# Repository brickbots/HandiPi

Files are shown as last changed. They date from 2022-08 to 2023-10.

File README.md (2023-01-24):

# HandiPi

Handheld RPI4 based computer with 36-key tactile keyboard and display

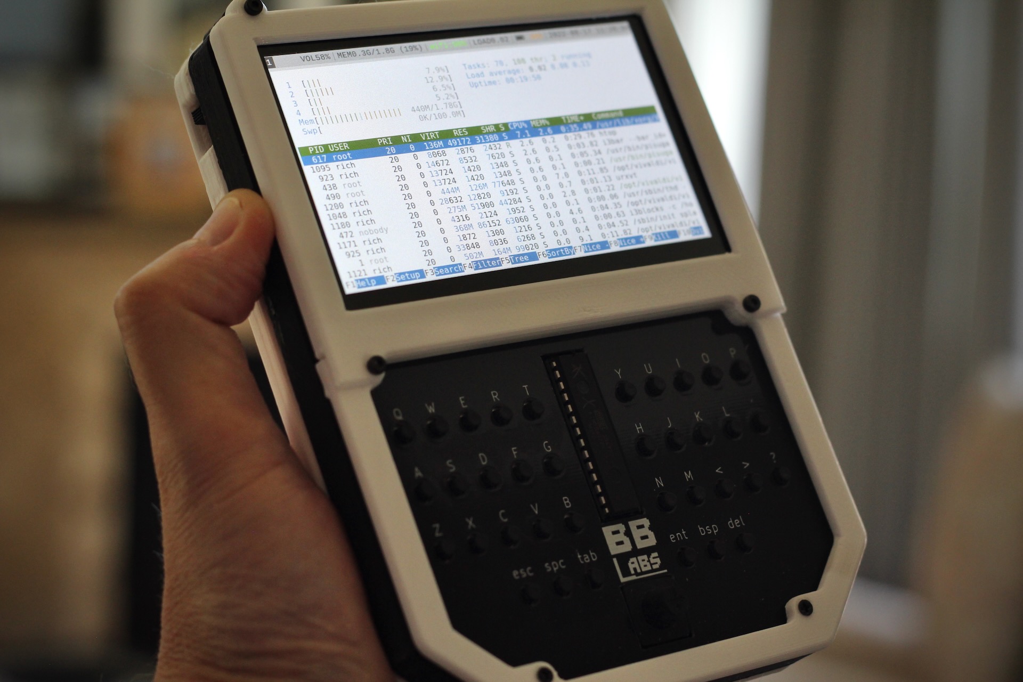
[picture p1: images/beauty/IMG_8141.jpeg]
The HandiPi


## What is it?

Glad you asked.. it's a fully functional linux computer with:
* A Raspberry Pi 4
* Custom 36-key keyboard with 5 way directional buton based around an Atmega328
* 4.3" DSI touchscreen display
* PiSugar power controller with 5000mah battery

It runs for about 4 hours with general terminal use and is pretty useful on it's own, but you can hook 
up external monitors and other USB peripherals if you need more screen or typing space.

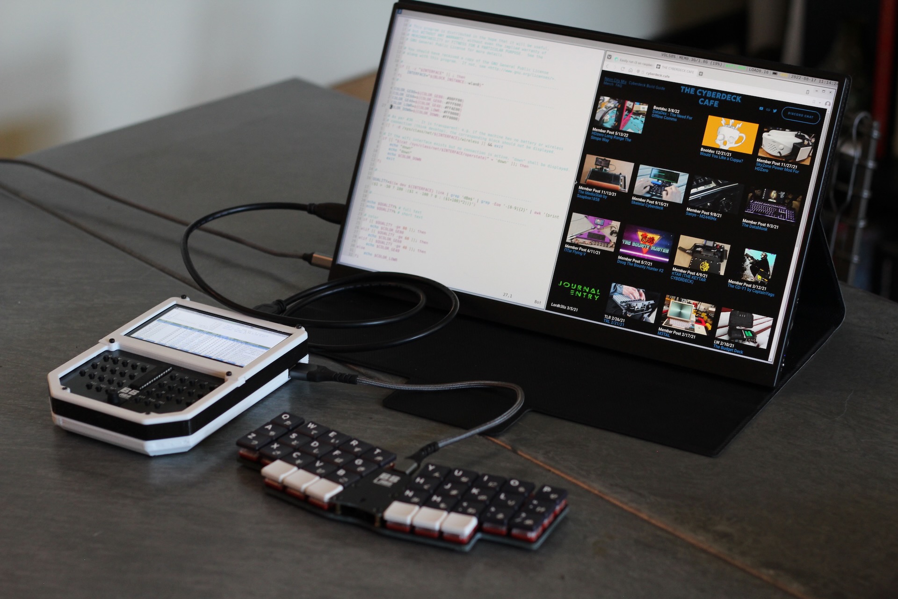
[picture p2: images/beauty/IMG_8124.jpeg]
Full work mode!


The keyboard runs QMK and interfaces to the Pi via USB, so it's fully configurable.  I really like the
[Miryoku](https://github.com/manna-harbour/miryoku) layout and use it on all my keyboards...so that's
what the physical button layout is based around.  The switches are Diptronic DTS63K tactiles with 1Nm 
of actuation force.  They look the same as the generic ones, but it's worth the few extra dollars as 
they feel so much better to type on.  It's still a thumb-typing experience, but the limited number of
keys and the well thought out layering system of Miryoku makes it a suprisingly useful keyboard!

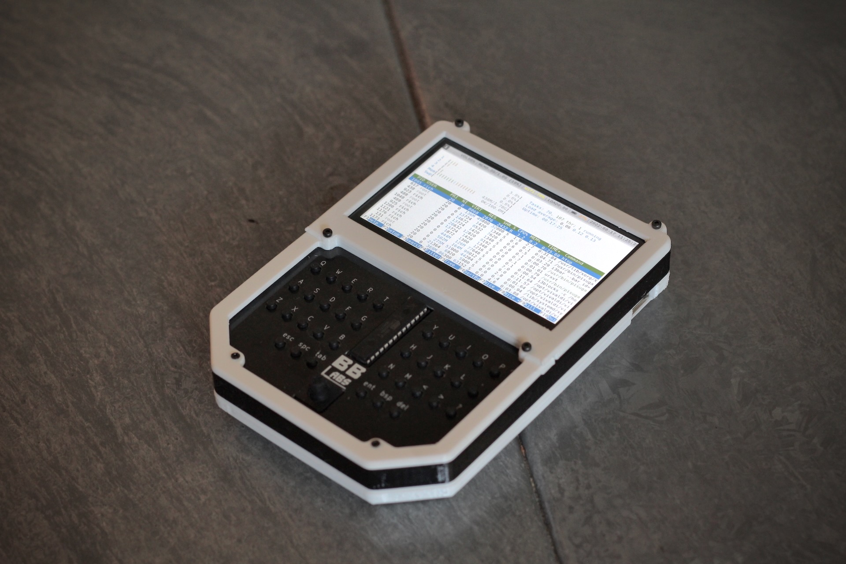
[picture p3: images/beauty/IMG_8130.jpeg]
It's a keyboard


## Oh god, why?

Well.. it all started when I picked up the PCB's for the 
[PICOmputer](https://www.tindie.com/products/bobricius/picomputer-rp2040-raspbbery-pico-qwerty-devkit/) 
made by [Bobricius](https://www.tindie.com/stores/bobricius/).  It's a sort of carrier board for the 
Raspberry Pi PICO that includes a keyboard using 6mm pushbutton tactile switches and a display.  It's 
simple, but it really opens up some fun potential.  I ended up 3d printing a case for mine and adding
a battery with charging to make it a neat little toy to play with.  Along the way, I was really
impressed with how well the keyboard actually worked.. even though I didn't follow his advice and bought
cheaper switches with higher actuation force.

When it came time to replace the Orange Pi based desktop PC I used at my workbench I grabbed the RPI4 I ordered
early in the pandemic and had been hording.  I was just going to put it in a boring case, but then I got 
to thinking about the PICOmputer and wondering if I could build a case with a screen and keyboard.  I'd 
still use the computer with a monitor, keyboard and trackball at my desk most of the time, but I could 
grab it and have my workbench computer with me if I wanted to go hack at a friends house or makerspace.

So that's where the idea came from, and the rest was just balancing the screen size with portability and
thinking hard about thumb-typing layouts....

## Designing a tiny keyboard

I've built a good number of keyboards in my time, and even [designed](https://github.com/brickbots/chocV)
a [couple](https://github.com/brickbots/slabv).  Most of the keyboards I've built rely on a pre-assembled 
Pro-Micro style controller, but I just didn't think I'd have the space to use that trick here.  There are 
many good refrence designs for the basic AtMega circuit, and I can
solder surface mount diodes okay, but I realy didn't think I'd have the skills to do a fine-pitch 
AtMega surface mount package without a lot of pain and suffering.  It was then that I remembered the first
keyboard I ever built.... the [Plaid](https://github.com/hsgw/plaid)!

The Plaid is a really neat 4x12 ortho keyboard built using ALL throughhole components!  It uses virtual
usb on an AtMega328 which is one of the few AtMega versions availabe in a DIPP package.  With this 
schematic in hand and information about the boot loader HSGW used, I started designing a new PCB.

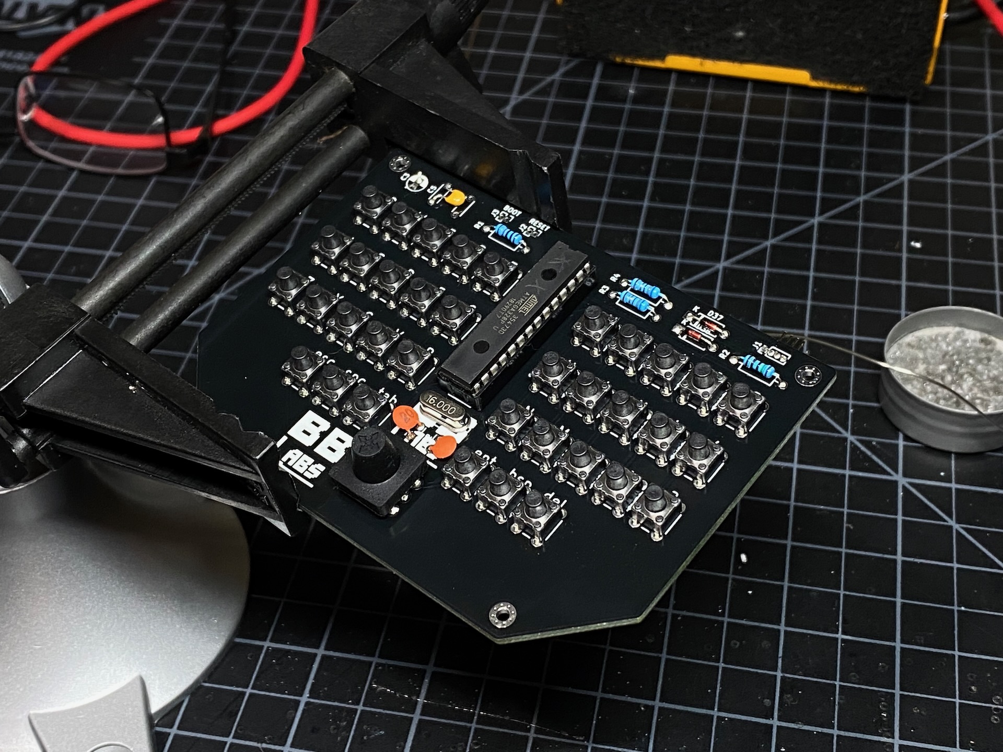
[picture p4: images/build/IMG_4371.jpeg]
It's a tiny keyboard


This is actually version 2... for the first one I thought I understood more than I did and left off the 3.6v
zener diodes on the USB data lines.  BTW, USB actually uses 3.6v signals!  Who knew?  I didn't know, so I 
thought the zeners were for overvoltage protection... They are not and many USB hubs/controllers won't work 
with 5v signal lines.  So, you need those if you are using a 5v MCU.

Here's a good place to thank [PCBWay](https://www.pcbway.com) for covering the cost of these boards.  Liam
reached out to me after seeing the [Framedeck project](https://github.com/brickbots/framedeck) with it's
custom keyboard/trackball PCB and asked me to give PCBWay a try with my next project.  I did, and they gave 
me a coupon to cover the cost, which was right nice of them.  The PCB's are not overly complicated, but the 
pricing was in line with other vendors, they arrived quickly, looked nice and clean and were fabbed to spec.
Overall, a nice experience and I'll definitely consider them again in the future.

So after two revisions, everything worked and it looks nice and tidy with the 1mm top PCB to cover the guts
and present nice legends.

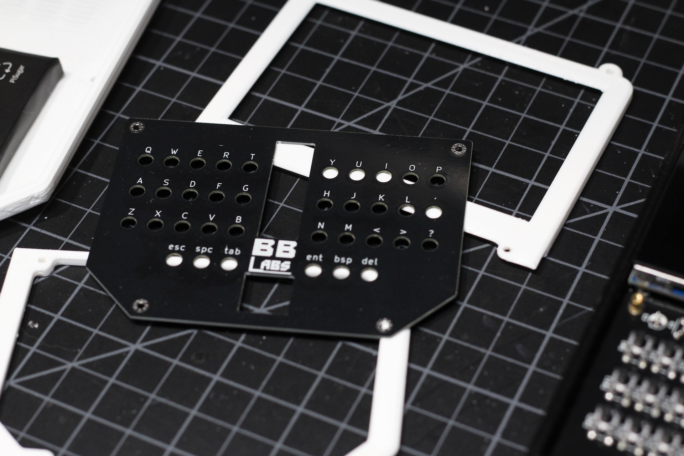
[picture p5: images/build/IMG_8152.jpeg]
KB Top plate


## OS and Navigation
This little bad-boy runs Raspberry Pi OS, a Debian derivitive, and I use i3 as my window manager.  This is
a great tiling window manager that I run on all my linux systems, but it's particularly well suited for 
resource limited machines as it's very light weight.  It's also very keyboard friendly, which helps as 
this unit does not have a great pointing device.  The touchscreen works okay for some things, and the 
Miryoku layout has support for mouse keys on a layer (which can be used with hjkl or the directional button)
, but I prefer keyboard interaction where possible.

i3 does have a good number of multi-key combos to get stuff done, and these are tricky with just two thumbs. 
It's possible to get another finger in the mix and still hold on, but I ended up using the directional button 
for a lot of the multi-key directional bits like focus left/right/up/down, resizing windows, or switching
desktops.  The directions are mapped to mod-h,j,k,l which will change window focus by default.  I can combine
this shift to move windows.  If I hold down the center directional button, the four directions change
between four desktops, and I can combine this with shift to move a window to a specific desktop!

There are some other less common combos (like defining vertical/horizontal splits) that can always be 
accessed using the actual key combos

## More info

Here's a photo of the back of the unit showing the HDMI, audio output, and charging port of the PiSugar. 
To the left (in the photo, right side of the unit) is the one available USB port on the RPI 4.  To make 
the whole thing thinner, I removed the ethernet jack and double USB ports.  One of the usb pinouts is 
run internally to talk to the keyboard, and I put a single-high USB jack on the other for external 
connections.

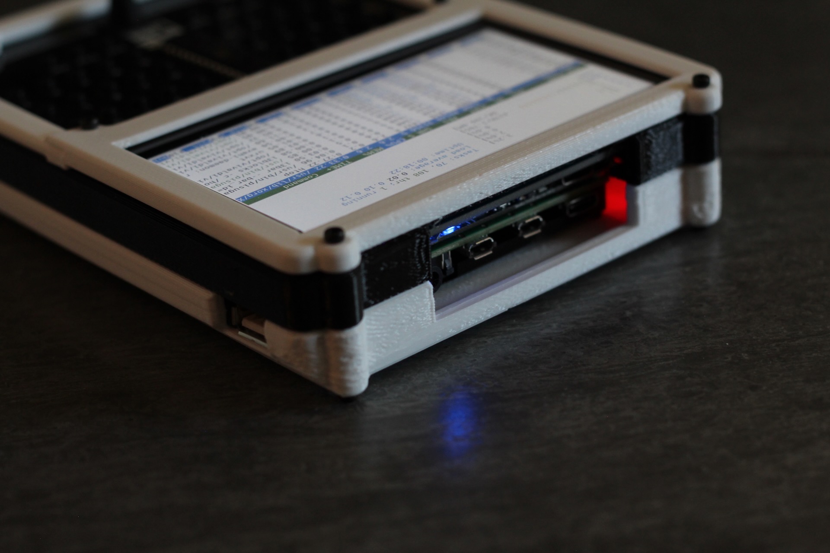
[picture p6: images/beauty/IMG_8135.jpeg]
Connections


If you'd like to learn more about how this was all put together check these links below:

* [Parts List](docs/BOM.md)
* [Build Tour](docs/build.md)

## Copyright and License

Copyright (c) 2022 Richard Sutherland. All rights reserved.

All files are licensed under MIT license
see the [LICENSE](LICENSE) for more information.

<a href='https://ko-fi.com/brickbots' target='_blank'>Buy Me a Coffee at ko-fi.com

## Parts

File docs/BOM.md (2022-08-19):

# HandiPi - BOM

This is not a comprehensive parts list.  You'll need some  M2/M2.5 hardware, wires and 
likely some other bits to build something similar.

## Main Components
Quantity|Item|URL
---|---|---
1|Raspberry Pi 3/4| 
1|Waveshare 4.3" DSI Display| https://www.amazon.com/gp/product/B088JTD6JN
1|PiSugar 2 Plus|https://www.amazon.com/Pisugar2-Portable-Platform-Raspberry-Accessories/dp/B08D8PPCKN
1|SD Card|

## Keyboard
Quantity|Item|URL
---|---|---
1|Keyboard Circuit PCB 1.6mm| /gerbers/handipi_kb.zip
1|Keyboard Cover PCB 1mm| /gerbers/handipi_kb-top-plate.zip
1|5way switch|https://www.adafruit.com/product/504
1|Rubber cover for 5way switch|https://www.adafruit.com/product/4697
36|6 x 6mm x 7mm PCB Momentary Switch 4 Pin DIP| Diptonics DTS63K 1nm recommended
36| 1N4148 SMT SOD-123 Diodes|
1|AtMega328 DIPP|
1|16mhz Crystal|
2|22p ceramic capacitor|
2|100n ceramic capacitor|
1|4.7u electrolytic capacitor|
2|3.6v zener diodes|
2|75ohm resistors|
1|1.5kohm resistor|
1|10kohm resistor|
4|4mm m2 standoffs|

## Misc Parts
Quantity|Item|URL
---|---|---
1|SPST Slide Switch| https://www.amazon.com/gp/product/B08232XVL5
2|USB PCB Mount port|
1|each 3d printed case sections| /printed_case
x|Various M2 standoffs / screws|

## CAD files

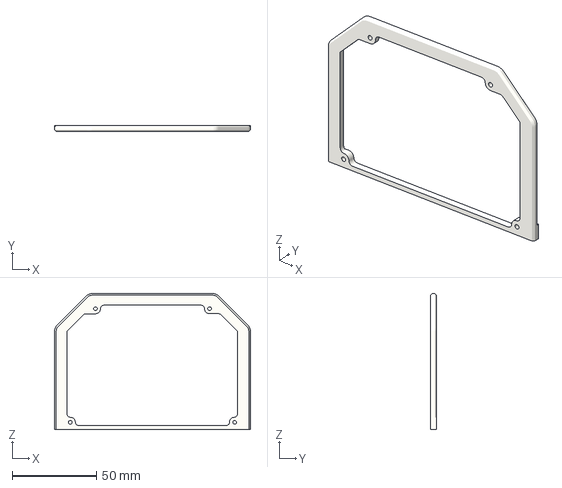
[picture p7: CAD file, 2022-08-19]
printed_case/kb_bezel.3mf
116.0 x 3.50 x 80.5 mm

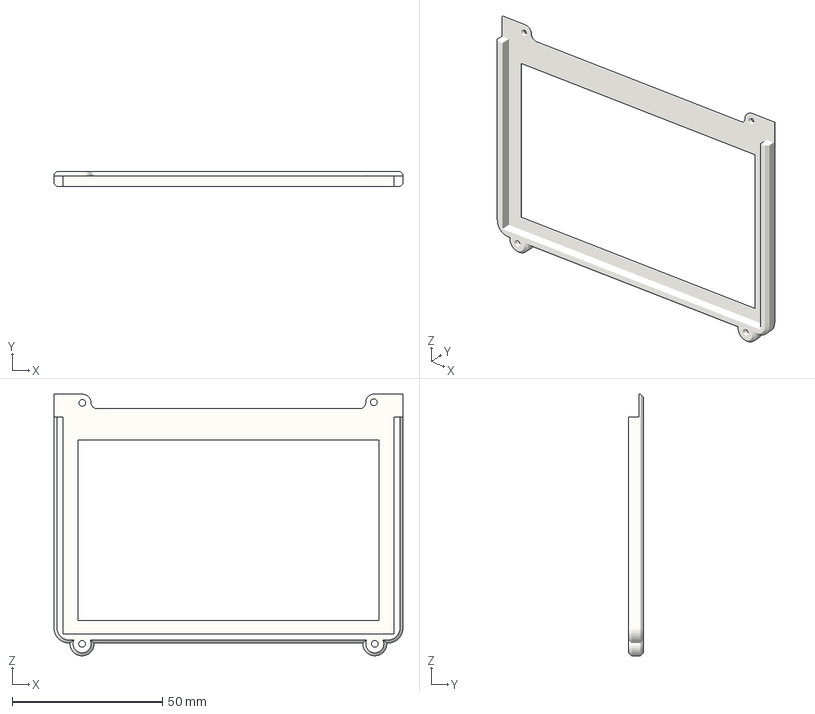
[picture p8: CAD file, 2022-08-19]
printed_case/screen_bezel.3mf
116.0 x 5.00 x 87.0 mm

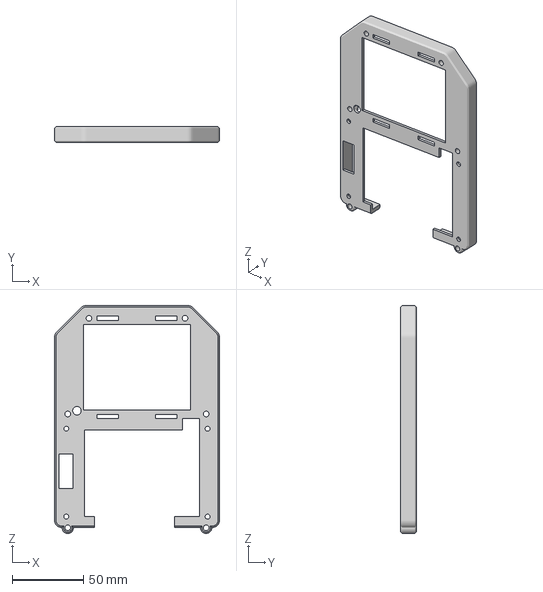
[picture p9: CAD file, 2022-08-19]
printed_case/middle.3mf
116.0 x 11.0 x 160.3 mm

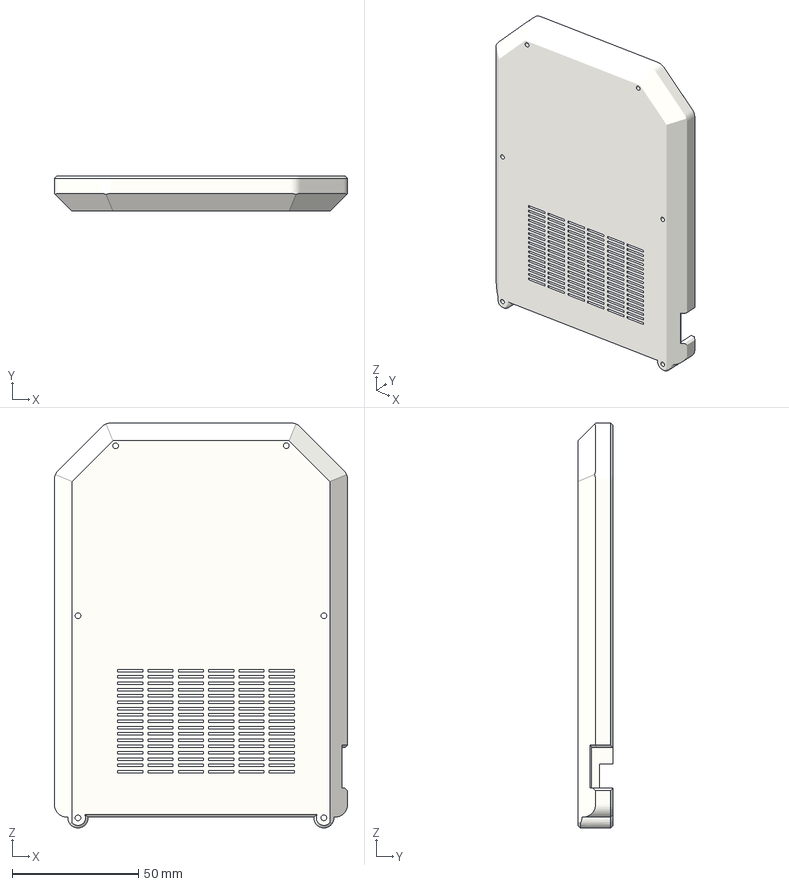
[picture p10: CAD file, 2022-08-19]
printed_case/bottom.3mf
116.0 x 14.0 x 160.3 mm

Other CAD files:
fusion360/HandyPi_Keyboard.f3d
fusion360/waveshare_4_3_dsi_LCD.f3d

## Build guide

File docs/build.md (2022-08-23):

# Build Tour

I'm calling this a tour, not a guide, as I'm more pointing out interesting things than
giving complete instructions on how to build one of these.  I hope there might be some 
neat tricks here I can share, or at least inspire you to build something similar for yourself. 

If you want to build this exact same item, check out the [Parts List](./BOM.md)... it lists 
pretty much everything you need and there are ready-to-order gerbers and ready to print parts
in this repo. Hopefully this tour will give you enough to put it together, but I'm happy to 
answer any questions you might have.  Now on to the tour!

## Overview

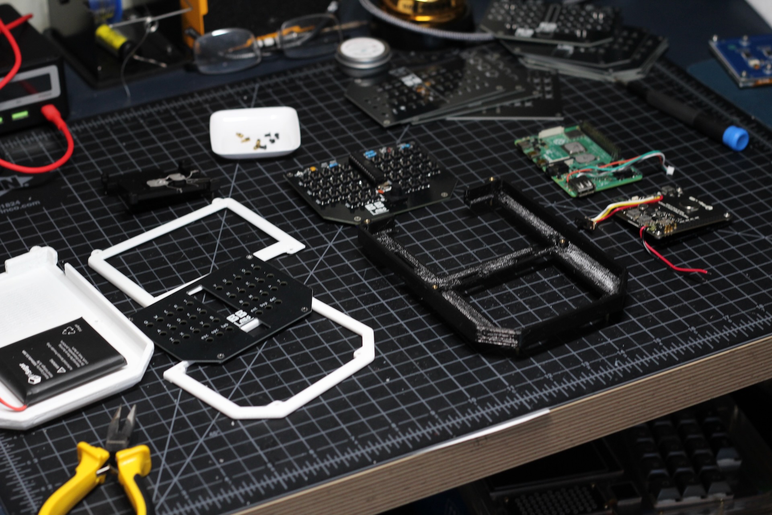
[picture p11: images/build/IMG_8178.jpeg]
The HandiPi


I couldn't quite get all the parts in one shot, but they are all visible here.  The screen being
partially visible and blurry there in the right corner of frame.  Roughly from left to right/top
to bottom
* Bottom 3d printed case + battery double sided taped in
* Heatsink (black with thermal paste)
* 3d printed screen and keyboard bezels + keyboard PCB overlay
* Keyboard PCB assembled
* 3d printed middle layer where most everything attaches to
* RP4
* PiSugar board
* Screen

## Pi slim-down

To keep the overall thickness down, I've removed the ethernet and double-high USB jacks from
the Pi.  This is not too delicate, but be slow and careful along the way.  For more info, 
Adafruit has a nice [guide](https://learn.adafruit.com/diet-raspberry-pi) to this process.
They did a much nicer job than I did :-)

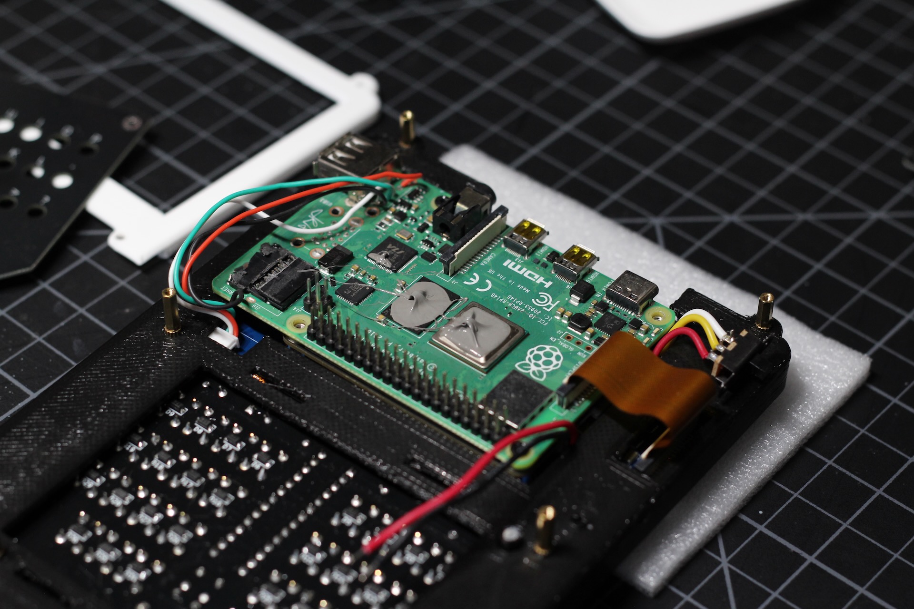
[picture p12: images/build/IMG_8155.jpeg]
Slim Down


I added back one single USB 2.0 port.  If you can cleanly remove the USB 3 port and solder a 
single high one back on then you are a better person than I am.  Just modify the case and you'll
have TWO external USB... one high speed!

I used the second set of USB pads from the double high jack to connect the keyboard. You can see 
this handy work, along with the crooked USB port (for shame!) here

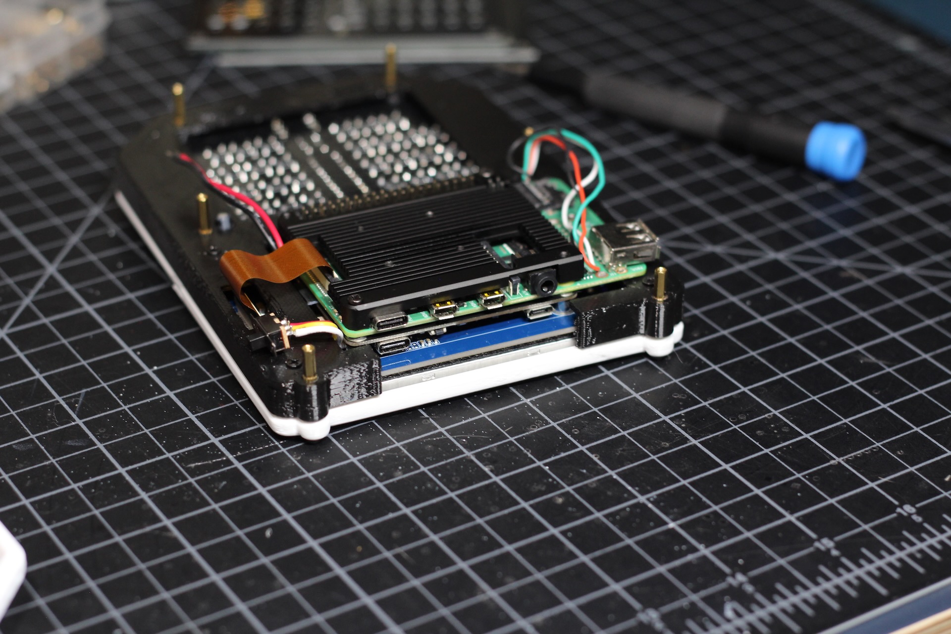
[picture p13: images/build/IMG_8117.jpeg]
From the back


## PiSugar Mods

I removed the battery socket as it was too tall to fit between the PiSugar and the case.  In it's 
place I soldered two solid heavy-ish gauge wires to connect the battery.  The original power switch
is kind of tiny and hard to get to when it's all mounted.  So I desoldered that and used a nice
chunky one that is friction mounted in the bottom of the case.

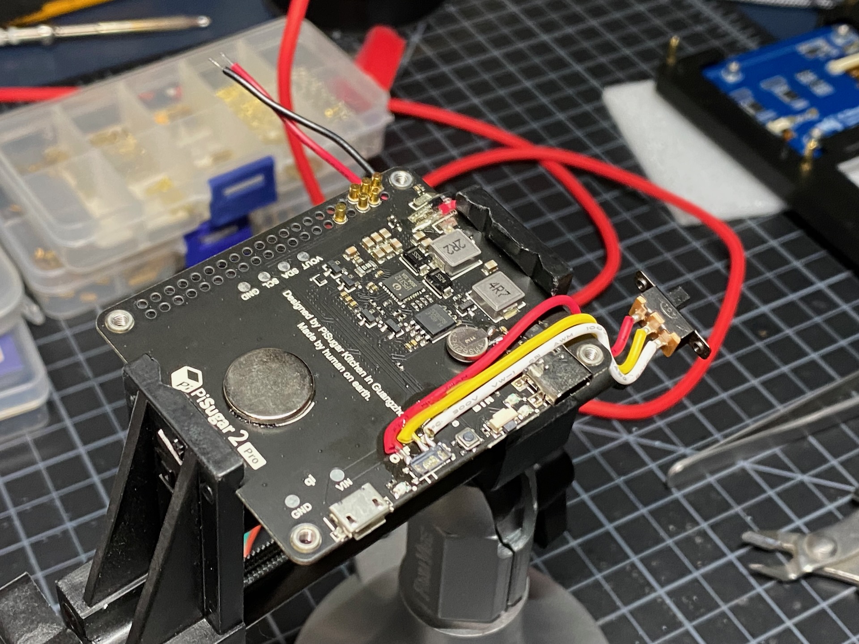
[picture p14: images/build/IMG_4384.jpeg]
PiSugar Mods

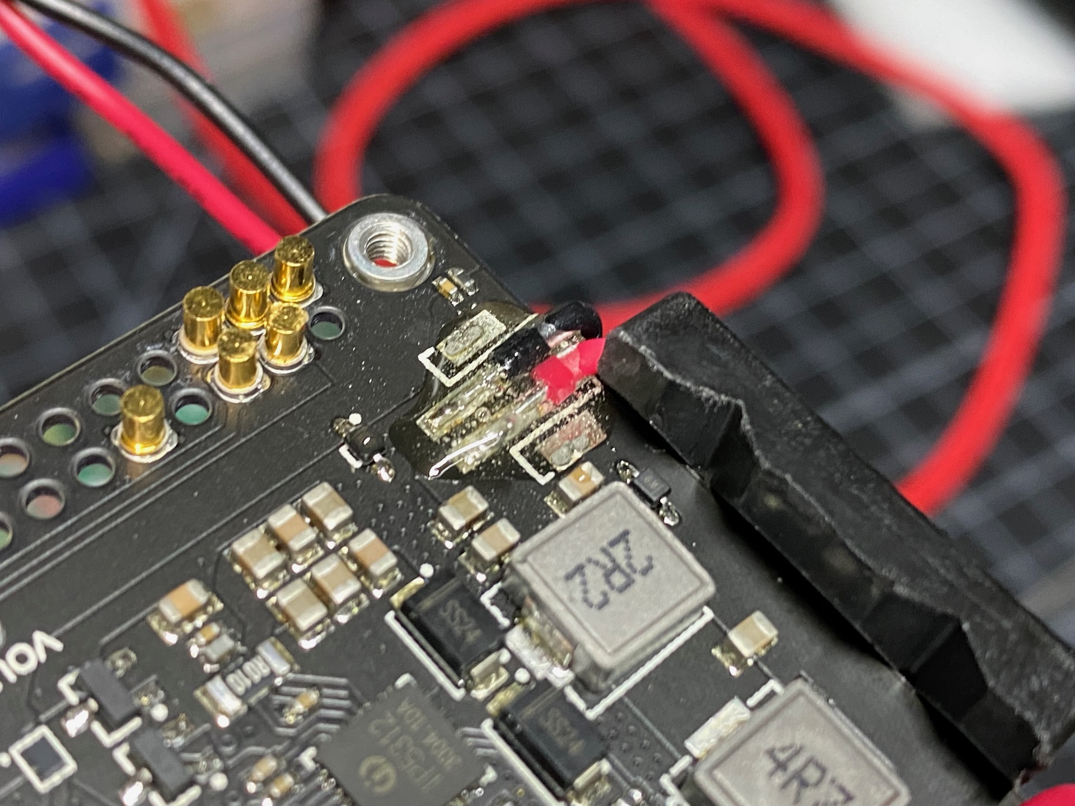
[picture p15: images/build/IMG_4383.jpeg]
Battery

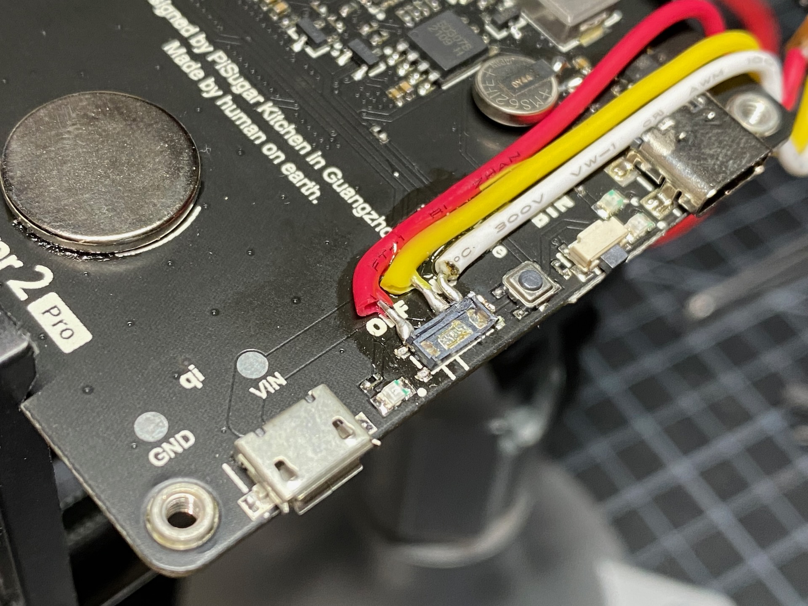
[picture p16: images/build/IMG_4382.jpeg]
Switch


I used epoxy around these mods as strain relief

## Keyboard

The keyboard has a 1.6mm double sided PCB with all the components on it, and a 1mm top plate
with no traces, just cutouts and silkscreened letters.  If you want to go stealth mode, you 
can flip it over and it's solid black!  [PCBWay](https://pcbway.com) covered the cost of these
to convince me to try them out.  I did, and they turned out great (Thanks Liam!).  The silkscreen is nice 
and sharp, which is great for the top cover.

Keyboard

It's pretty easy to build as it's mostly through hole.  I'd suggest doing everything but the 
diodes/switches firt then flash and test before doing the surface mount diodes and finally the
switches.  Check the [schematic](./handipi_kb_schematic.pdf) for values on the components.

The elecrolytic capacitor goes on the BACK of the board as it's a bit too tall to fit well
under the keyboard cover.  There is a hole in the middle section to provide clearance.  The 
4 pin header can probably work on either side, but I put it on the bottom side and there is
a cutout in the middle section to fit the plug from the Pi.

For details about the vusb design and the specific bootloader I used, please see the 
repo for [the Plaid](https://github.com/hsgw/plaid) keyboard.  Once the bootloader 
is installed, it's standard QMK all the way.  For this specific layout, try
[Miryoku!](https://github.com/manna-harbour/miryoku)

## Case + Assembly

The case is 4 parts: middle, bottom and two top bezels. 3mf files are provided for these and I
printed them in my favorite filement, Colorfabb Ngen with a 0.6mm nozle and .3mm layer height.

### Middle

Most everything mounts to the middle (black) section.  It has M2 heat set inserts which 
faciliate all this mounting.  These 4 inserts for the keyboard are a bit longer than the middle 
is thick and protrude a bit from the bottom.  This is to allow good threading from both sides.

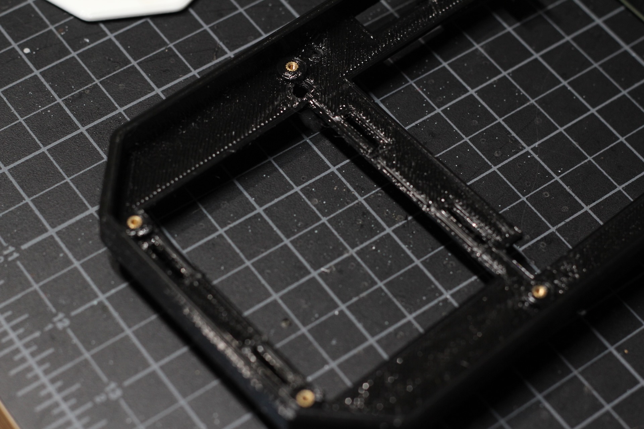
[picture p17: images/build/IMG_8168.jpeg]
Keyboard Inserts


The keyboard screws to the 'top' of these inserts and there are long stand-offs which extend down
and serve as attachment for the bottom.  There are 4 more inserts in the two upper holes, one on top
and one on the bottom.  One really long insert might work, but I didn't have one to try and two 
seemed reasonable

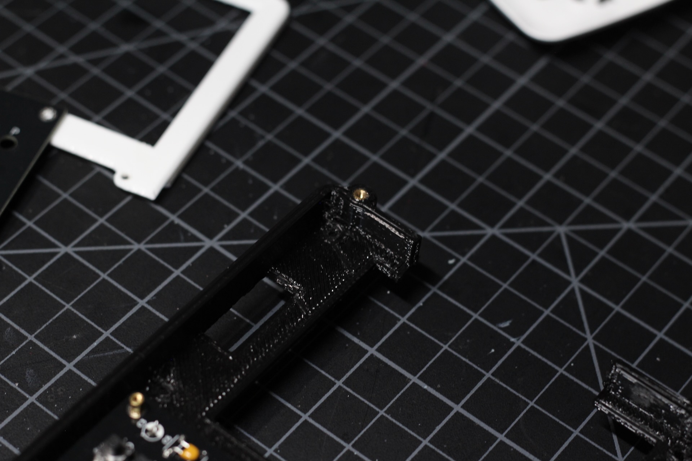
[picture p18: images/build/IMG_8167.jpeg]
Upper inserts


The screen I used had it's own threaded posts, so m3 screws secure the screen to the middle section
from the bottom.  You can see the screen here before and after mounting in these two photos.
You can also see the long stand-offs which allow attachment of the case bottom.

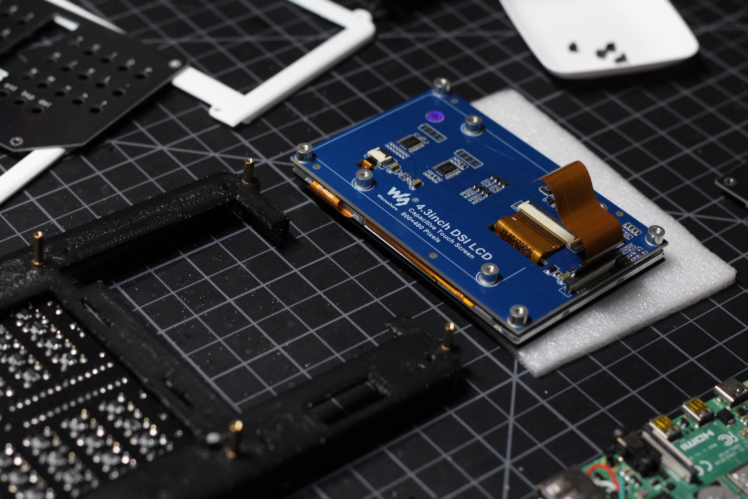
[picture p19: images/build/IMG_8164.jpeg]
Before mounting

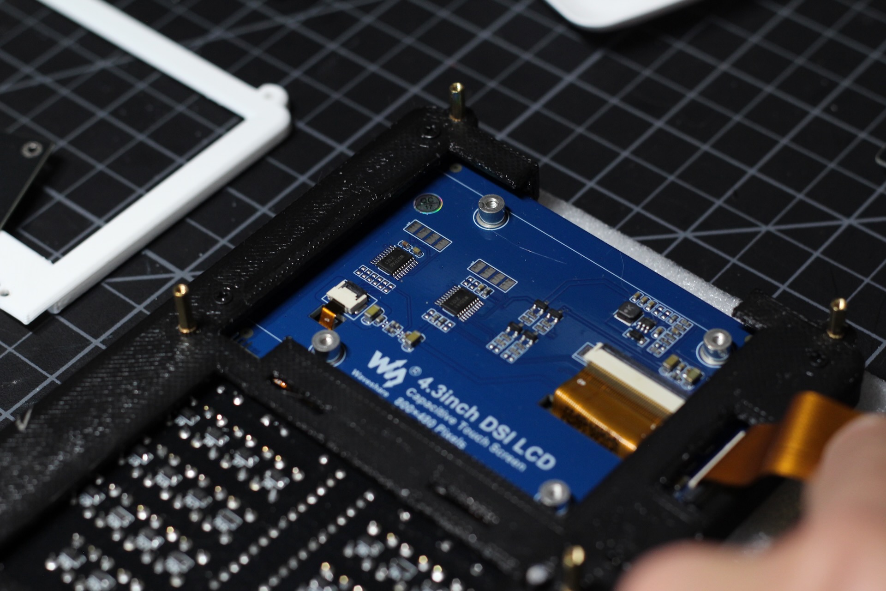
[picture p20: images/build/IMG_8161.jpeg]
After mounting


Once the screen is mounted, the PiSugar and Pi4 mount to it in a sandwich along with the heatsink.  The
screen has threaded posts to mount the Pi, but the PiSugar is also threaded... I was woried I would not 
be able to get them to mate tightly, but it worked out fine without much trouble. 

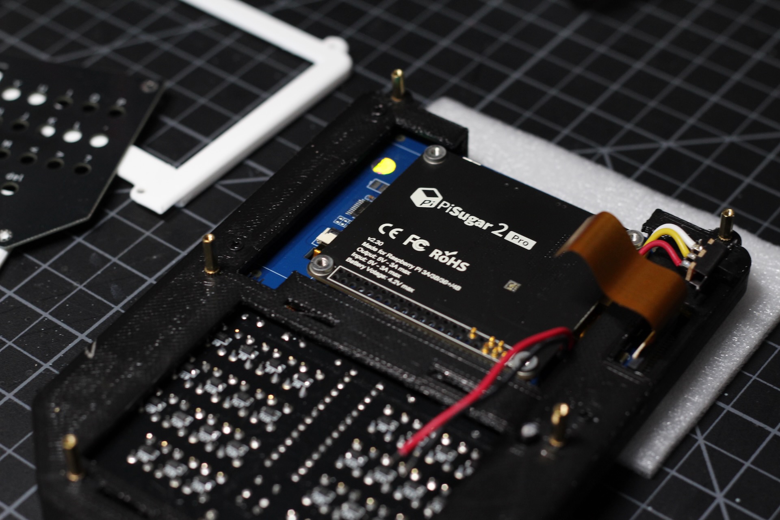
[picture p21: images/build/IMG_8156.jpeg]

Pi + Sugar

My particular heatsink also screwed in to this unholy sandwich, but none of the screws I had were long
enough to go through the heatsink, PI, pisugar and thread into the screen.  So two screws hold the 
pi/sugar to the screen and the other two corner screws go through the heatsink into just the piSugar. 
It sounds janky, but it's all very tight and secure.

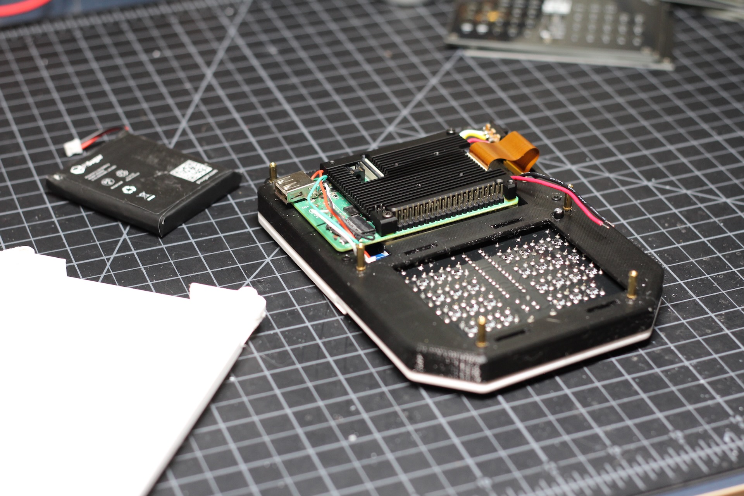
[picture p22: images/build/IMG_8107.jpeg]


The keyboard affixes to the top side of the middle section with threaded 4mm stand-offs.  You can see
it all mounted, along with the screen, here:

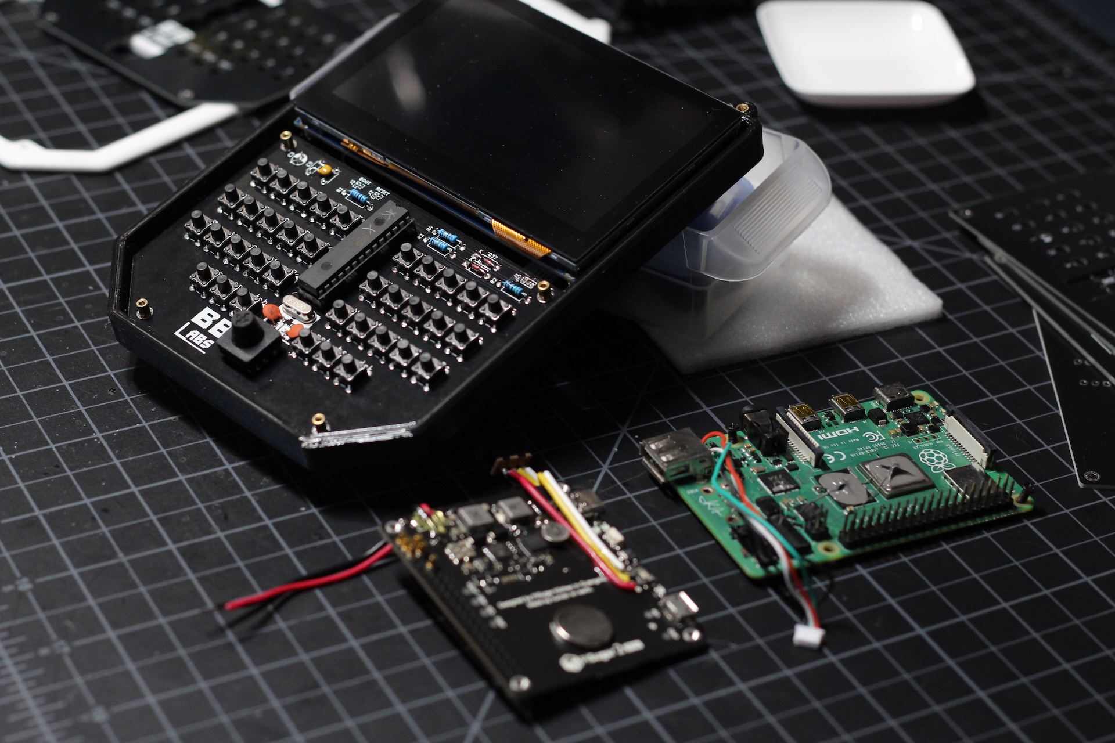
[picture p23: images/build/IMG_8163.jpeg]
Keyboard in place


The keyboard can be tricky to plug in once it's mounted so you might want to take care of that before
screwing it down.

Once everything is mounted, double check that you have the screen plugged in and the keyboard connected
and you can move on to the bottom/bezels. 

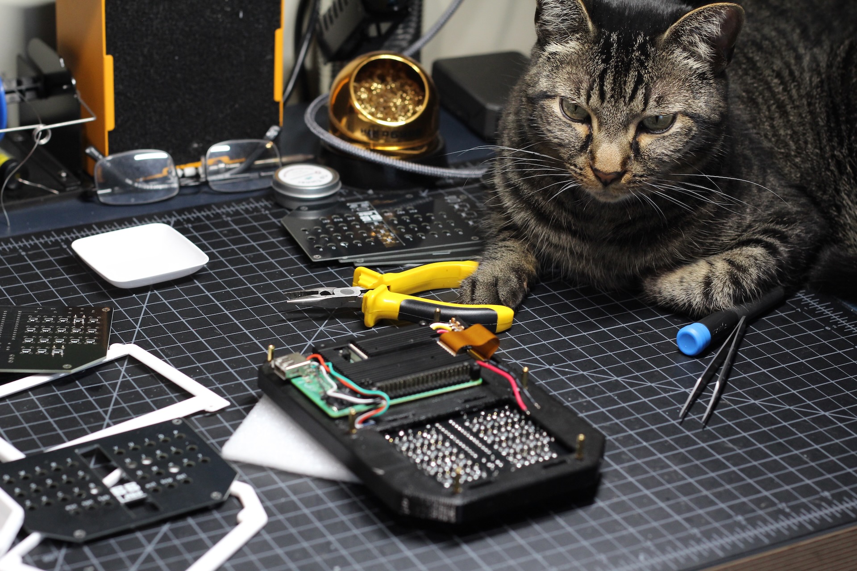
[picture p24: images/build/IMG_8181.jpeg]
Double check wiring


I feel like my cat was judging my work here.....

### Bottom

Just secure the battery to the bottom of the case, clean up the print and it should fit in without any
dramas.  The switch fits into the side of the bottom case and might need some convincing.  Secure
the bottom to the middle layer with M2 bolts through the bottom into the long stand-offs.  I used hex
head bolts here to raise the bottom of the unit off the tabletop for ventilation.

## Bezels

There is a screen and keyboard bezel that tidy up the top.  They fit over the top PCB plate for the 
keyboard

Bezels

Once you've got the bottom on, flip it over and place the printed PCB over the keyboard. 

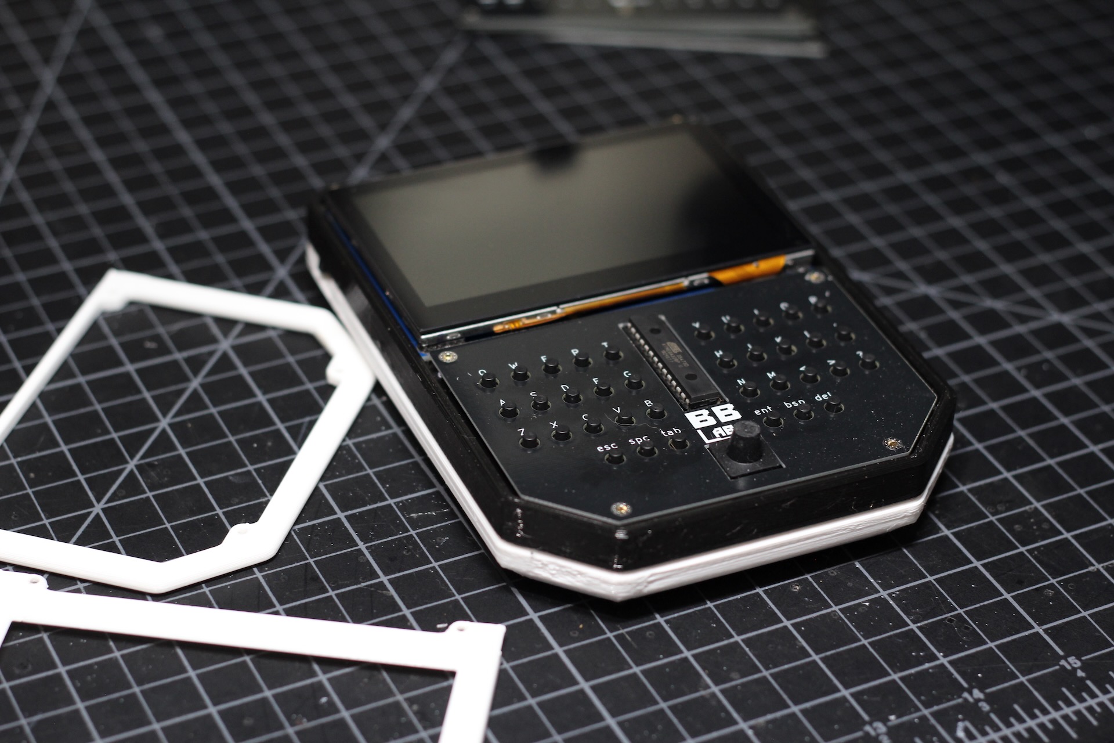
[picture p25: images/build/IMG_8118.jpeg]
Keyboard cover


The keyboard bezel goes on first, and the screen bezel fits on top of it.  Then secure everything with
6 m2 screws.  I used hex head screws for the 4 around the screen to match the bottom, but I used flat
top screws for the lower ones to clear the typing path.

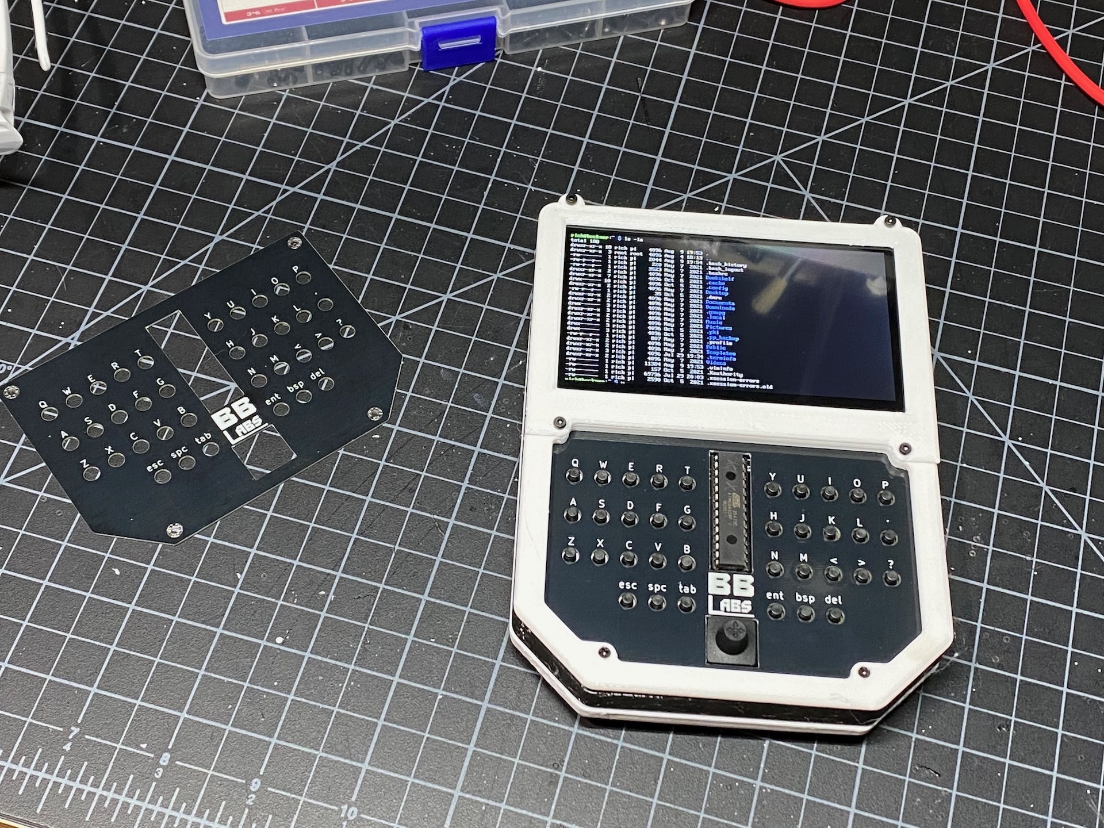
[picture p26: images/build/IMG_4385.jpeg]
You're done!


That's pretty much it!  Install the OS of your choice and happy handheld hacking!  Email if you have 
any questions or just want to share your work.

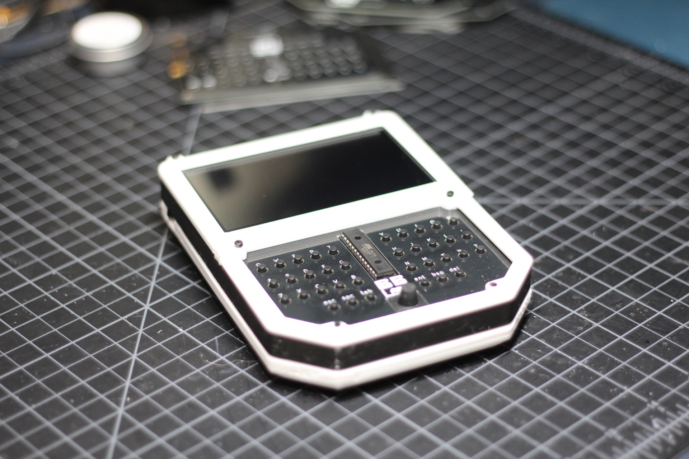
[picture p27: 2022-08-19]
images/build/IMG_8105.jpeg

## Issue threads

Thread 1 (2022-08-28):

Issue: I don't have one

sgtbane, 2022-08-28:
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

I have a 3d printer to make the case parts. I would be comfortable possibly f-ing up my rpi4 and removing/replacing its components if it was at msrp. At around $200(cad) I can't justify it. I'll be making the attempt if the prices ever come down. this is an Awsome build and something I have been looking for a while now!

thank you!

kloontim, 2022-08-28:
+1

jreniel, 2022-08-28:
I wish I would be able get this off the shelf! Been dreaming about something like this for a looong time!

brickbots, 2022-08-29:
Hi @sgtbane and Co!

Thanks for the awesome 'issue' here :-)   The general lack of availability of Pi's and the danger of destroying one is definitely the largest stumbling block here....

I've been meaning to take some of my PCB design skills up a notch and experiment with getting boards fully built/populated by the fabricator.  If I had those skills, this project could be re-imagined as a compute module carrier with USB/HDMI/Audio + power management all on one board which the compute module plugs into.  It could probably be a bit thinner, easier to produce for sale, and much easier to build.

I'd also like to offer it with at least two keyboard layouts... 36% and something closer to a standard 60%.

Wouldn't solve the problem of compute modules being almost impossible to get, but it would make the whole project much simpler and open up the possibility of a group by of some sort.

For now, I'm happy to provide any advice I can.  Just let me know if anyone has questions and thanks so much for the awesome feedback!

sp00ck, 2022-08-30:
How many days this device work on one charging?
Why this is fat?

brickbots, 2022-08-30:
Hi @sp00ck !  It runs for about 4 hours with general terminal and light web browsing use.  That can be extended by turning off wifi/down screen brightness to 5 or 6 if you are just editing code and such.

The thickness is required to fit the stack of the screen, pisugar and RPI4.  Here's a cut-away showing the arrangement:
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

There is absolutely room for a larger battery which could double the runtime, I've just not found need for it yet :-)

sp00ck, 2022-09-02:
i no need device with small working time

Mortuus-Medicus, 2022-09-08:
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

This project is basically PocketCHIP but with Raspberry Pi. If the price is too high, maybe try looking into getting PocketCHIP in the secondary market, but do keep in mind that the company that made then is dead, so software for  device including its standalone CHIP are mostly just in the open source community now. That's where Raspberry Pi has a huge advantage! Still worth the look though.

I am surprised that PocketCHIP wasn't mentioned anywhere, since it's basically the same thing. I guess that's why people say we did twice.

Closed 2022-08-29.

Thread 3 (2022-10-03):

Typo

AkariiinMKII, 2022-10-03:
https://github.com/brickbots/HandiPi/blob/6356b704d89582fd6fa2a959ced833687f7c6ed6/README.md?plain=1#L22

 Here might be `1mm` I guess :P

brickbots, 2022-10-04:
Haha!  I see the confusion.. it's 1 Newton Meters of force, not nano-meter :-). I just checked and the N should be capitalized, I supposed to avoid this specific issue!

Closed 2022-10-04.

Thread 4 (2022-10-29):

How to build QMK for HandiPi?

inajob, 2022-10-29:
let me know how to build QMK for this project?

I see https://github.com/manna-harbour/miryoku_qmk/tree/miryoku/users/manna-harbour_miryoku, but I don't know which is best setting for this project.

nobodYZH, 2022-11-05:
same question.
please help.

nobodYZH, 2022-11-05:
same problem, can anyone help?

brickbots, 2022-11-06:
Hi Hi!

Thanks for giving the HandiPi a try!  Sorry for the delayed response, I'm on holiday currently.  I can provide a bit more help when I return, but I have checked in all the QMK files in a branch on my fork:

https://github.com/brickbots/qmk_firmware/tree/handypi/keyboards/handipi

Hopefully this will provide most of what you need.  You can either copy these files into your own fork, or checkout mine and build with the command:

`make clean handipi:manna-harbour_miryoku:flash MIRYOKU_ALPHAS=QWERTY MIRYOKU_NAV=VI`

Replacing which ever Miryoku options you like.  There is also a default keymap to start from if you don't want to use Miryoku.

Hope this helps!  I'll check back in the next day or two to answer any followup questions :-)

nobodYZH, 2022-11-06:
Thank you for your reply, that helps me a lot!

nobodYZH, 2022-11-06:
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

Thank you for your reply, that helps me a lot!

nobodYZH, 2022-11-07:
I build qmk and flash the keyboard successfully, and the Miryoku layout works well. But the directional button seems not working.

brickbots, 2022-11-07:
Hi @nobodYZH !  Thanks for letting me know you got it all up and running.

I didn't include anything for the directional button as it was mapped pretty specifically to my I3WM config and I was not totally sure I implemented it in the 'correct' way to work with Miryoku and

 wanted to review the best practices there.

When I have a bit of time to rework this part of the keymap and make sure it's not going to break other things, I'll push the changes to the same branch.  In the meantime, the directional button is wired up in the matrix as the 5th row and it setup properly in config.h.  Here is how the directions map to the columns:

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

Let me know if you have any other questions I can help with!

inajob, 2023-02-25:
Thank you! Mine also worked!
I also had to set fuse bit.

`lfuse 0xEF, hfuse 0xD9, efuse 0xFE`

brickbots, 2023-02-25:
Hi @inajob !  So glad to hear it worked out for you.  Thanks for letting me know you got it working 👍

inajob, 2023-02-28:
and I wrote an blog article of making of this keyboard in Japanese.

https://inajob.hatenablog.jp/entry/2023/02/28/HandiPi%E3%81%AE%E6%89%8B%E3%81%AE%E3%81%B2%E3%82%89%E3%82%B5%E3%82%A4%E3%82%BA%E3%81%AE%E3%82%AD%E3%83%BC%E3%83%9C%E3%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

brickbots, 2023-02-28:
Hi Hi!

That's a wonderful article!  I had to have it machine translated for me, but it was well ordered and informative.  Thank you for sharing your experience :-D

Closed 2022-11-08.

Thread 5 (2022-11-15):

Issues with V-USB implementation in schematics

sini6a, 2022-11-15:
Hi brickbots,

You did a fantastic work here and I would really like to try get this thing to work.

Right now I have some issues with the keyboard. I have flashed usbaspLoader modified to work with Atmega328P used in Plaid keyboard. Everything goes well, I flashed your qmk config on the keyboard but i constantly get some issues with USB resets and HID errors. The strange thing is that this heppens only with the firmware flashed and not while in bootloader.

Other strange thing is that the keyboard works sometimes on my computer while getting HID errors but never on Rasberry Pi 4.

What I tried so far:
1. Changing different fuses on the chip
2. Replacing the chip with new one (tought this could be the issue because I heated the first one badly)
3. Built another new keyboard with 68R instead of 74R
4. Changed USB cable

I am using male USB cable, it is not yet soldered on the Pi, could this maybe related to the errors?

I am stuck and I would be thankful if you have some suggestions for diagnosing this issue.

sini6a, 2022-11-15:
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

brickbots, 2022-11-15:
Hi @sini6a !  Sorry to hear about the bumps you've run into here.  From the photos your build looks very clean and nice and I don't see anything out of place.

As a next step, I would suggest making your USB 'cable' as short as possible.  Normal USB cables are generally well shielded and constructed to prevent interference.  Using bare wires like the HandiPi does, means that the run needs to be as short as possible.  Also try to make the two data lines the same length, within reason.

I had some similar issues with a longer test cable I created and they went away when I made the cable much shorter.  Hopefully this will help you as well!

brickbots, 2022-11-15:
Just looking a bit closer at your photos... the capacitor in the upper-left (C1) is specified as an electrolytic.  Not sure exactly what the type/value is of the component you've used, but this is part of the power filter/smoothing and it could conceivable lead to some voltage fluctuations if it's not quite right.

I'd definitely suspect the wire/cable length first, but this might be another thing to try if you are still having issues.

sini6a, 2022-11-16:
Thank you for fast response @brickbots!

The cable length is 15cm. I will try and cut them to half of the current length.

As of the capacitor I think you mean C3 which is located on the upper left corner of the image. It is a 4.7uF ceramic capacitor. I will attach more specification below of the order.

I also noticed that without 1n4148s I got it to work on Raspberry but it was lagging and often stuck on keypress. I think this could be related to USB resets.

I am trying your suggestions first and I will keep you updated.

Thank you for your time 😊

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

brickbots, 2022-11-16:
Hi Hi!

Yes, I did mean C3, thank you :-). I've never seen a solid electrolytic before, I'm used to the cylindrical aluminium ones, pretty neat!   That should totally work fine, so hopefully it's just the cable.

It's interesting that it worked without the diodes.... are you referring to D37/D38?  If so, those are not general purpose signal diodes, they are zener diodes to assure that the USB signal lines are 3.6v rather than 5.  My first prototypes without them worked on some devices, but not others, depending on how tolerant the host was of the over-voltage USB data lines.

sini6a, 2022-11-17:
Hello again 🙂

I was reffering to

sini6a, 2022-11-17:
Hello again 🙂

Actually I was referring to small signal diodes that should be on the keys. I removed them all and will test without them first. I got them from another supplier and thought that maybe they did some mistake about the model but I will investigate this further when my other order arrives.

Those two diodes sit in place. I will send more specification about them below.

I am still not able to report anything because I was busy these days. Will do it in the weekend latest and report back.

I really appreciate your help and the time spend here trying to resolve the issue. 😊

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

brickbots, 2022-11-17:
Those are definitely the correct Zener diodes!  Good luck with your experiments over the weekend!

sini6a, 2022-11-18:
Hi again!

No luck so far. I cut the cable half of the length, same problem.

I tried measuring the voltage on D lines, I am not sure what values should I read but in one of the lines (D+) I get 2.30 idle and 1.20V on key pressed. Other line (D-) has 5.20V idle and 3.20V on key press.

Is it allowed for this line to go over 3V?

Thank you 😊

sini6a, 2022-11-18:
Okay I have update:

On R2 I installed one more resistor with value of 1.74kOhm and it works like charm.

I don’t have enough technical knowledge to describe why is it so, maybe someone can explain.

One question that I have right now is does this means that I need to put 3.24kOhm instead of 1.5kOhm?

Thank you so much for your help! 😊

![Uploading image.jpg…]()

sini6a, 2022-11-18:
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

brickbots, 2022-11-19:
Hi Hi!

So glad it's working, but it's definitely a bit mysterious... R2 pulls the D- line high, indicating that the usb connection is low-speed and 1.5k is the recommended value here.

Adding resistors in parallel, as the photo indicates, actually produces a lower resistance than either resistor's value.  In this case ~0.8k.... even stranger!   Might be interesting to test the combined resistance without the circuit powered.

As for the D-/D+ voltages, these will be tricky to measure without a good oscilloscope as they will be shifting between low and high states very quickly.  However, it should generally not read above 3.6v.    I'd be curious to know the voltages across the two Zener diodes if you can power the board but leave the signal lines unconnected.

All that aside, if it works, it works!  Glad you worked through the problem and got it sorted :-)

sini6a, 2022-11-20:
Hi!

Yes, that was the solution in my case, been testing for a whole day and didn’t get a single USB reset.

Really strange because all schematics on the internet shows 1k5 or 1k7 resistance on the line.

I am traveling this week but I would be happy to do some more tests and report back as soon as I get back. It would be interesting to learn why this board acts like this.

I will close the thread as solved for now. Huge thanks for your help and keep up the good work. This device is brilliant. 😊

Closed 2022-11-20.

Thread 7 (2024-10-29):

how only two diodes?

HamBrick327, 2024-10-29:
I'm trying to learn some circuits myself, and I'm having trouble understanding how ghost inputs are prevented with only two diodes, also given how the schematic says every key has it's own diode. Thanks!

EDIT: I'm also not sure what the diodes are being used for, I think its USB D+ and D-, but I'm not very confident.

brickbots, 2024-10-30:
Hello HamBrick!

Thank you for checking out the HandiPi and I hope it helps you in your learning.  The two diodes on the top of board are zener diodes which are used to limit the voltage on the USB data lines to 3.3 volts, rather than the 5 volts the microcontroller is using.

The diodes for adding multi-key press capabilities to the keyboard are surface mounted on the back of the board.  You can see them as the little dark-grey components in the photo below:

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

I'm happy to answer any questions you might have and good luck on your electronics design journey!

HamBrick327, 2024-11-09:
that makes a lot more sense. I don't know how I missed that looking at the kicad files. Thanks for the help!

Closed 2024-10-30.

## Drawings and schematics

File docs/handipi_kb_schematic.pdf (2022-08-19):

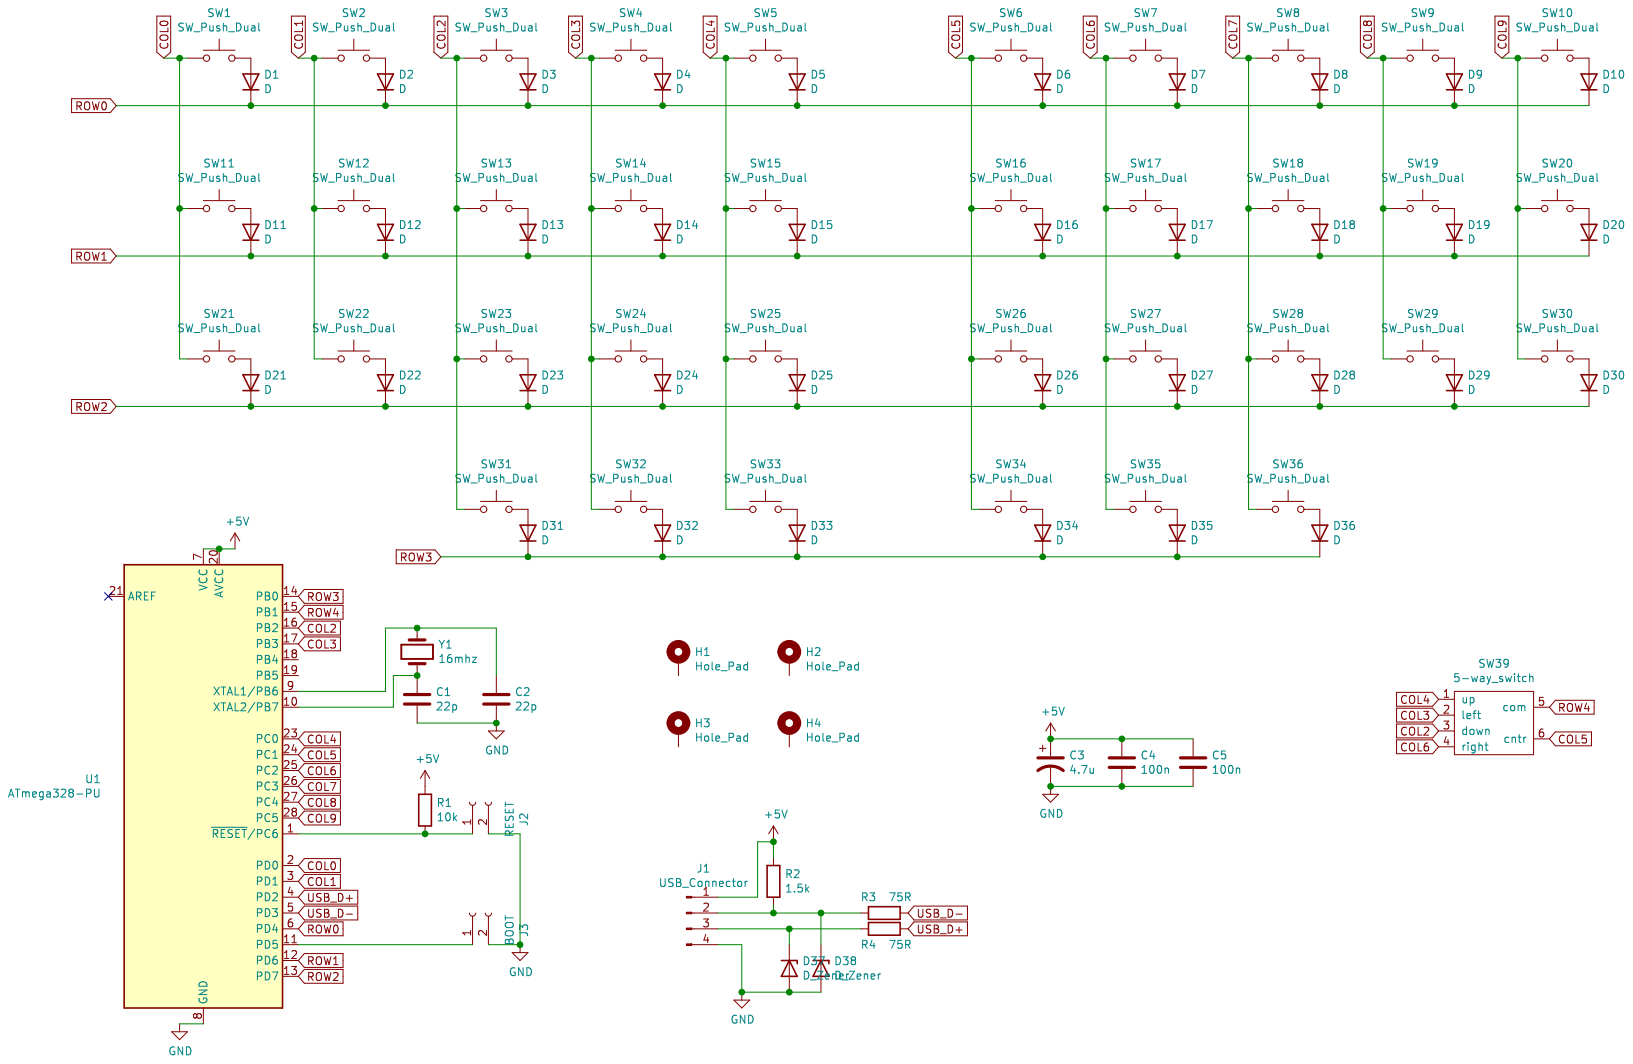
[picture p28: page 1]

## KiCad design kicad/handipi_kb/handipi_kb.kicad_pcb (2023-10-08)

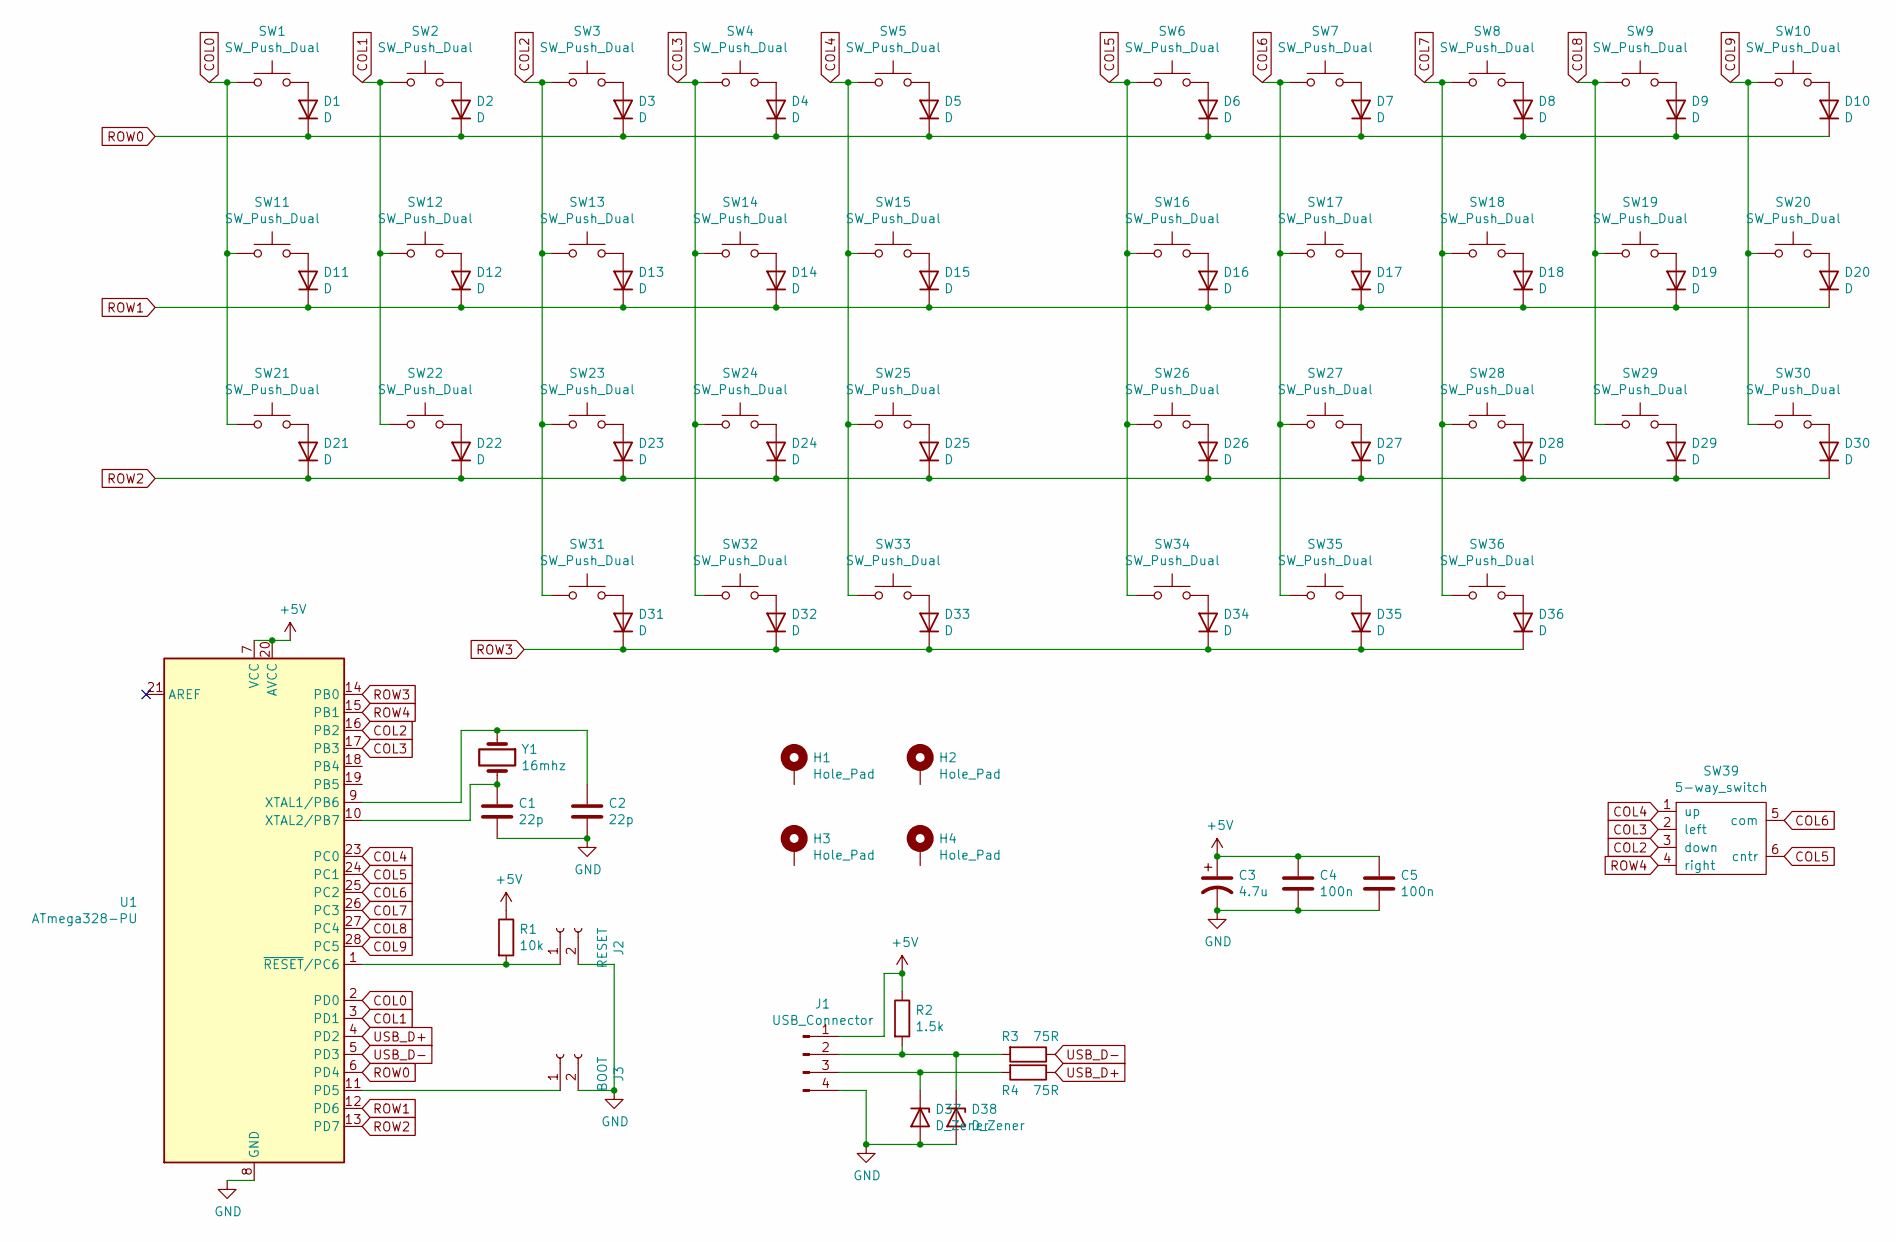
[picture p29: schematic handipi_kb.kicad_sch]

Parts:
C1, C2: 22p; C_Disc_D3.0mm_W2.0mm_P2.50mm
C3: 4.7u; CP_Radial_D4.0mm_P1.50mm
C4, C5: 100n; C_Disc_D4.3mm_W1.9mm_P5.00mm
D1, D2, D3, D4, D5, D6, D7, D8, D9, D10, D11, D12, D13, D14, D15, D16, D17, D18, D19, D20, D21, D22, D23, D24, D25, D26, D27, D28, D29, D30, D31, D32, D33, D34, D35, D36: D; D_SOD-123
D37, D38: D_Zener; D_A-405_P7.62mm_Horizontal
H1, H2, H3, H4: Hole_Pad; Mount_M2
J1: USB_Connector; PinHeader_1x04_P1.27mm_Vertical
J2: RESET; PinHeader_1x02_P1.27mm_Vertical
J3: BOOT; PinHeader_1x02_P1.27mm_Vertical
R1: 10k; R_Axial_DIN0207_L6.3mm_D2.5mm_P10.16mm_Horizontal
R2: 1.5k; R_Axial_DIN0207_L6.3mm_D2.5mm_P10.16mm_Horizontal
R3, R4: 75R; R_Axial_DIN0207_L6.3mm_D2.5mm_P10.16mm_Horizontal
SW1, SW2, SW3, SW4, SW5, SW6, SW7, SW8, SW9, SW10, SW11, SW12, SW13, SW14, SW15, SW16, SW17, SW18, SW19, SW20, SW21, SW22, SW23, SW24, SW25, SW26, SW27, SW28, SW29, SW30, SW31, SW32, SW33, SW34, SW35, SW36: SW_Push_Dual; SW_PUSH_6mm_with_hole
SW39: 5-way_switch; switch_5way
U1: ATmega328-PU; DIP-28_W7.62mm
Y1: 16mhz; Crystal_HC18-U_Vertical

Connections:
+5V: C3.1, C4.1, C5.1, J1.1, R1.1, R2.1, U1.7 (VCC), U1.20 (AVCC)
COL0: SW1.1, SW11.1, SW21.1, U1.2 (PD0)
COL1: SW2.1, SW12.1, SW22.1, U1.3 (PD1)
COL2: SW3.1, SW13.1, SW23.1, SW31.1, SW39.3 (down), U1.16 (PB2)
COL3: SW4.1, SW14.1, SW24.1, SW32.1, SW39.2 (left), U1.17 (PB3)
COL4: SW5.1, SW15.1, SW25.1, SW33.1, SW39.1 (up), U1.23 (PC0)
COL5: SW6.1, SW16.1, SW26.1, SW34.1, SW39.6 (cntr), U1.24 (PC1)
COL6: SW7.1, SW17.1, SW27.1, SW35.1, SW39.5 (com), U1.25 (PC2)
COL7: SW8.1, SW18.1, SW28.1, SW36.1, U1.26 (PC3)
COL8: SW9.1, SW19.1, SW29.1, U1.27 (PC4)
COL9: SW10.1, SW20.1, SW30.1, U1.28 (PC5)
GND: C1.2, C2.2, C3.2, C4.2, C5.2, D37.2 (A), D38.2 (A), J1.4, J2.2, J3.2, U1.8 (GND), U1.22 (GND)
unnamed: C1.1, U1.10 (XTAL2/PB7), Y1.2
unnamed: C2.1, U1.9 (XTAL1/PB6), Y1.1
unnamed: D1.2 (A), SW1.2
unnamed: D2.2 (A), SW2.2
unnamed: D3.2 (A), SW3.2
unnamed: D4.2 (A), SW4.2
unnamed: D5.2 (A), SW5.2
unnamed: D6.2 (A), SW6.2
unnamed: D7.2 (A), SW7.2
unnamed: D8.2 (A), SW8.2
unnamed: D9.2 (A), SW9.2
unnamed: D10.2 (A), SW10.2
unnamed: D11.2 (A), SW11.2
unnamed: D12.2 (A), SW12.2
unnamed: D13.2 (A), SW13.2
unnamed: D14.2 (A), SW14.2
unnamed: D15.2 (A), SW15.2
unnamed: D16.2 (A), SW16.2
unnamed: D17.2 (A), SW17.2
unnamed: D18.2 (A), SW18.2
unnamed: D19.2 (A), SW19.2
unnamed: D20.2 (A), SW20.2
unnamed: D21.2 (A), SW21.2
unnamed: D22.2 (A), SW22.2
unnamed: D23.2 (A), SW23.2
unnamed: D24.2 (A), SW24.2
unnamed: D25.2 (A), SW25.2
unnamed: D26.2 (A), SW26.2
unnamed: D27.2 (A), SW27.2
unnamed: D28.2 (A), SW28.2
unnamed: D29.2 (A), SW29.2
unnamed: D30.2 (A), SW30.2
unnamed: D31.2 (A), SW31.2
unnamed: D32.2 (A), SW32.2
unnamed: D33.2 (A), SW33.2
unnamed: D34.2 (A), SW34.2
unnamed: D35.2 (A), SW35.2
unnamed: D36.2 (A), SW36.2
unnamed: D37.1 (K), J1.3, R4.2
unnamed: D38.1 (K), J1.2, R2.2, R3.2
unnamed: J2.1, R1.2, U1.1 (~RESET/PC6)
unnamed: J3.1, U1.11 (PD5)
ROW0: D1.1 (K), D2.1 (K), D3.1 (K), D4.1 (K), D5.1 (K), D6.1 (K), D7.1 (K), D8.1 (K), D9.1 (K), D10.1 (K), U1.6 (PD4)
ROW1: D11.1 (K), D12.1 (K), D13.1 (K), D14.1 (K), D15.1 (K), D16.1 (K), D17.1 (K), D18.1 (K), D19.1 (K), D20.1 (K), U1.12 (PD6)
ROW2: D21.1 (K), D22.1 (K), D23.1 (K), D24.1 (K), D25.1 (K), D26.1 (K), D27.1 (K), D28.1 (K), D29.1 (K), D30.1 (K), U1.13 (PD7)
ROW3: D31.1 (K), D32.1 (K), D33.1 (K), D34.1 (K), D35.1 (K), D36.1 (K), U1.14 (PB0)
ROW4: SW39.4 (right), U1.15 (PB1)
USB_D+: R4.1, U1.4 (PD2)
USB_D-: R3.1, U1.5 (PD3)

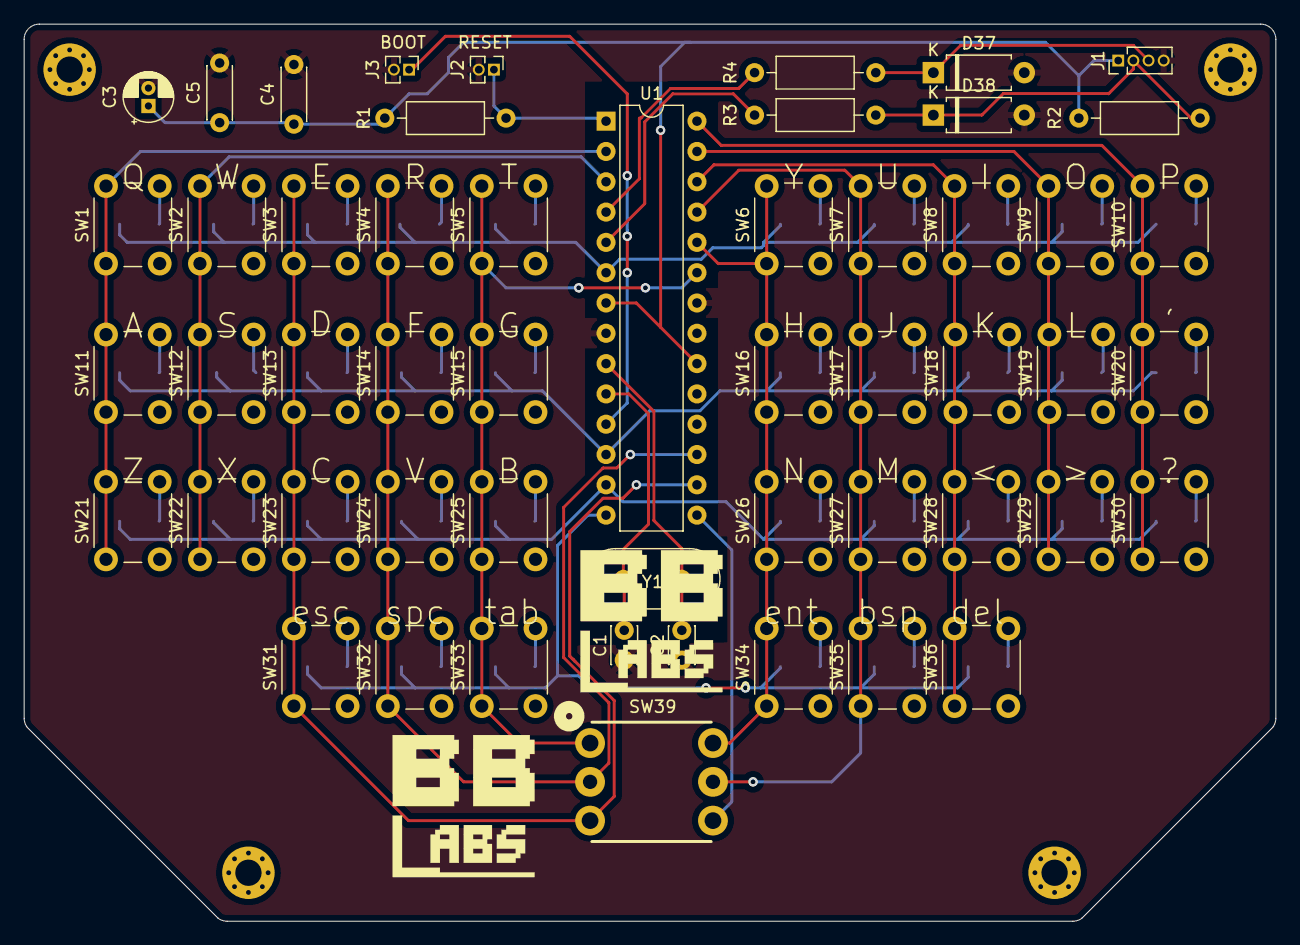
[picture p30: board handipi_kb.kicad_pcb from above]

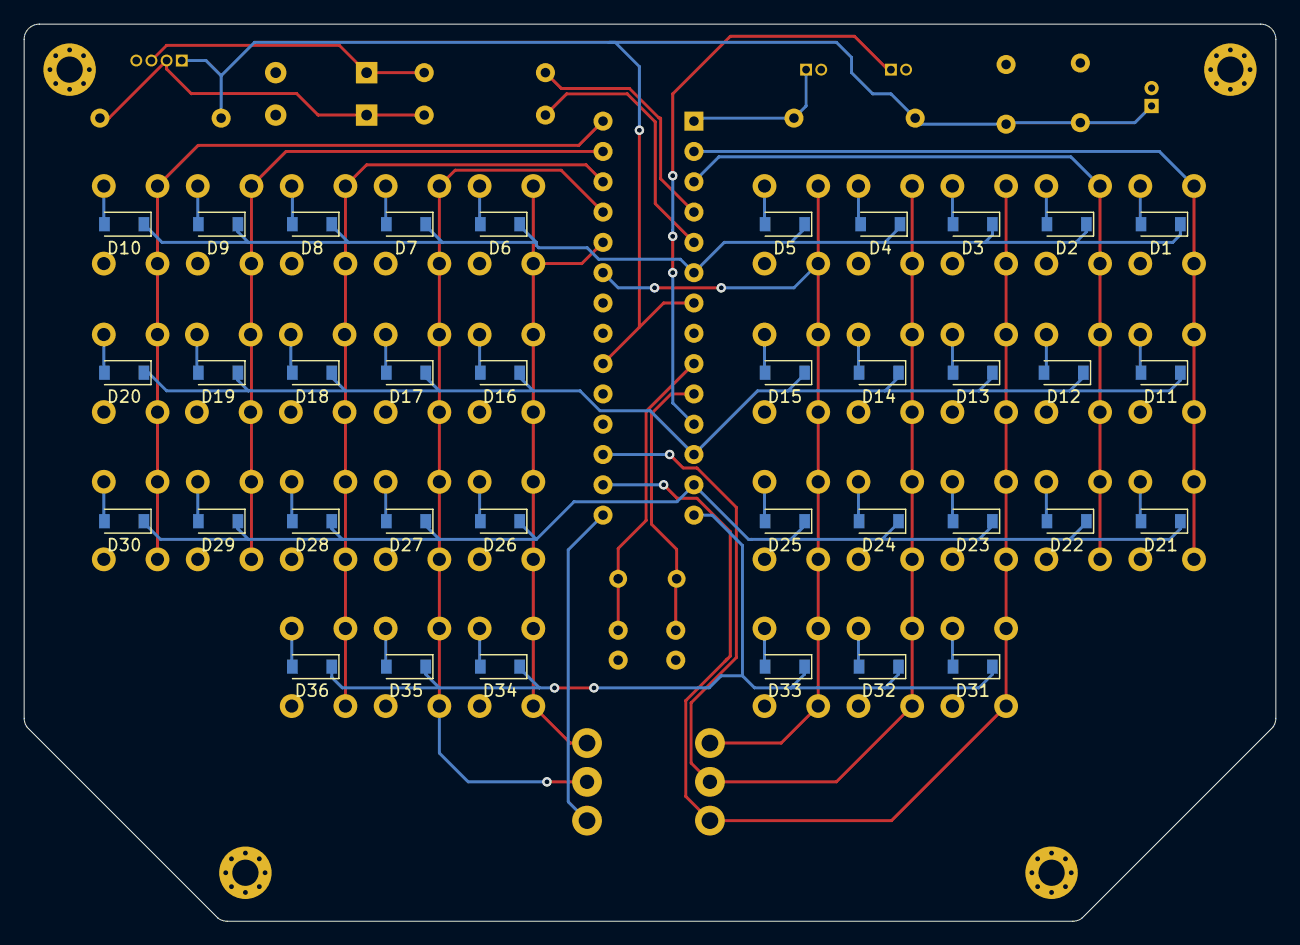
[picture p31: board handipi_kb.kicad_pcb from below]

Board: 2 copper layers, 104.9 x 75.2 mm, 95 parts (36 on the bottom side), 61 nets.

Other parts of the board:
LOGO1: LOGO1; bblabs_logo_sml
PCBLogo: PCBLogo; bblabs_logo_sml

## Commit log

2022-06-04 WIP kb
    [handipi_kb.kicad_pcb, handipi_kb.sch]
2022-07-31 Clean up structure and V1
    [bottom.3mf, handipi_kb-Edge_Cuts.dxf, handipi_kb-F_CrtYd.dxf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]
2022-08-19 Starting docs
    [HandyPi_Keyboard.f3d, bottom.3mf, handipi_kb-Edge_Cuts.dxf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]
2023-04-13 Fix footprint for directional switch
    [handipi_kb.kicad_pcb, handipi_kb.kicad_sch]
2023-10-08 Fix ground connection for col 6
    [handipi_kb.kicad_pcb]
